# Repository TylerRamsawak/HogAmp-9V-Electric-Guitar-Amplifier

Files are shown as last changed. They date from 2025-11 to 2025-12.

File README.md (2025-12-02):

# HogAmp: 9V Electric Guitar Amplifier
I made a very simple, portable guitar amplifier. Its based off the LM386N-1 and is designed to run off a single 9V battery. I travel a lot to-and-fro school and bringing my 10W amp, while small, is becoming annoying. Its a bit too big to fit in a backpack and needs mains ac to run. With my amp, these problems are gone in exchange for power and quality. However, for practice, this is not a concern to me. The HogAmp's name is inspired by the Pignose brand of amps. Those are too expensive for me, so here is my compromise!
<br>
### 3D Render of Enclosure
render_top
render1
render_lid

<br>
<div class="table_component" role="region" tabindex="0">
<table>
    <caption>BOM</caption>
    <thead>
        <tr>
            <th>Reference</th>
            <th>Quantity</th>
            <th>Value</th>
            <th>LCSC ID</th>
            <th>Price</th>
            <th>Ext. Price</th>
        </tr>
    </thead>
    <tbody>
        <tr>
            <td>U1</td>
            <td>1</td>
            <td>LM386N-1</td>
            <td>N/A</td>
            <td>$0.85</td>
            <td>$1.70</td>
        </tr>
        <tr>
            <td>C1,C3</td>
            <td>2</td>
            <td>10uF</td>
            <td>N/A</td>
            <td>$0.09</td>
            <td>$0.18</td>
        </tr>
        <tr>
            <td>C2</td>
            <td>1</td>
            <td>1000uF</td>
            <td>N/A</td>
            <td>$0.30</td>
            <td>$0.30</td>
        </tr>
        <tr>
            <td>C4</td>
            <td>1</td>
            <td>330nF</td>
            <td>N/A</td>
            <td>$0.18</td>
            <td>$0.18</td>
        </tr>
      <tr>
            <td>J1,J3</td>
            <td>2</td>
            <td>Toggle Switch</td>
            <td>N/A</td>
            <td>$0.47</td>
            <td>$0.94</td>
        </tr>
      <tr>
            <td>J4,J5,J7</td>
            <td>3</td>
            <td>10k Log. Potentiometers</td>
            <td>N/A</td>
            <td>$0.50</td>
            <td>$1.50</td>
        </tr>
      <tr>
            <td>J4,J5,J7</td>
            <td>3</td>
            <td>Potentiometer Dust Seals</td>
            <td>N/A</td>
            <td>$0.04</td>
            <td>$0.12</td>
        </tr>
      <tr>
            <td>J2</td>
            <td>1</td>
            <td>1/4" Female Jack</td>
            <td>N/A</td>
            <td>$0.87</td>
            <td>$1.74</td>
        </tr>
      <tr>
            <td>BT1</td>
            <td>1</td>
            <td>9V Clip</td>
            <td>N/A</td>
            <td>$0.10</td>
            <td>$0.10</td>
        </tr>
        <tr>
            <td>Total: $6.67 + $16.44(cheapest shipping & tariff)</td>
        </tr>
      <tr>
            <td>Grand Total: $23.20</td>
        </tr>
    </tbody>
</table>
</div>
I bought some extras incase I blew something up. Also, since when was shipping so expensive?! This is the cheapest option. In the future, I will buy bulk components all at once.
<h3>3D Model</h3>

<h3>PCB</h3>

<h3>Schematic</h3>


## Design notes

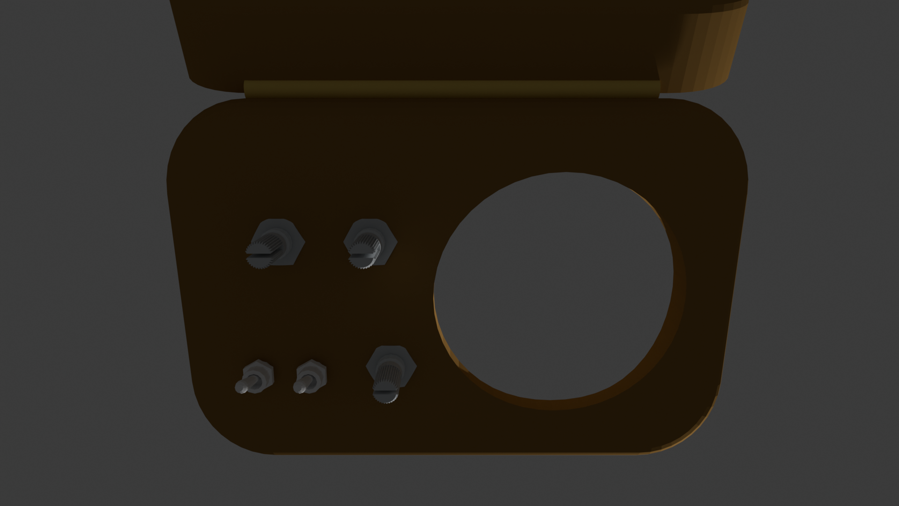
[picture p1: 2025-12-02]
render_lid.png

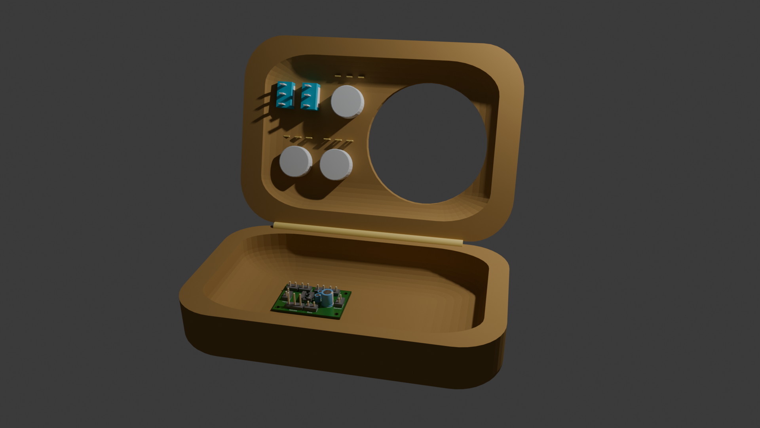
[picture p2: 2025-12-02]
render_side.png

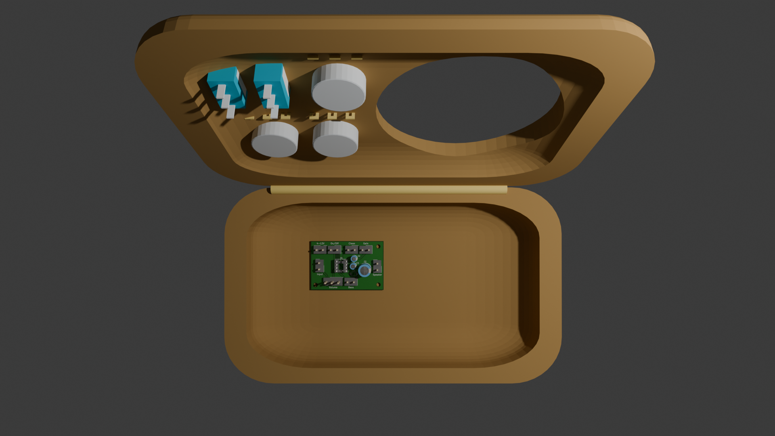
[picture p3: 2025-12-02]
render_top.png

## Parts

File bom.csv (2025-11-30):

Designator | Footprint | Quantity | Value | LCSC Part #
BT1 | Samtec_HPM-02-05-x-S_Straight_1x02_Pitch5.08mm | 1 | 9V
C1, C3 | CP_Radial_D5.0mm_P2.50mm | 2 | 10uF
C2 | CP_Radial_D10.0mm_P5.00mm | 1 | 1000uF
C4 | CAPRB500W50L450T300H550 | 1 | 330nF
J1 | Samtec_HPM-02-05-x-S_Straight_1x02_Pitch5.08mm | 1 | Power
J2 | Samtec_HPM-02-05-x-S_Straight_1x02_Pitch5.08mm | 1 | Jack
J3 | Samtec_HPM-02-05-x-S_Straight_1x02_Pitch5.08mm | 1 | Crunch
J4 | Samtec_HPM-02-05-x-S_Straight_1x02_Pitch5.08mm | 1 | Gain
J5 | Samtec_HPM-02-05-x-S_Straight_1x02_Pitch5.08mm | 1 | Bass
J6 | Samtec_HPM-02-05-x-S_Straight_1x02_Pitch5.08mm | 1 | Speaker
J7 | Samtec_HPM-03-01-x-S_Straight_1x03_Pitch5.08mm | 1 | Volume
U1 | DIP-8_W7.62mm_Socket | 1 | LM386

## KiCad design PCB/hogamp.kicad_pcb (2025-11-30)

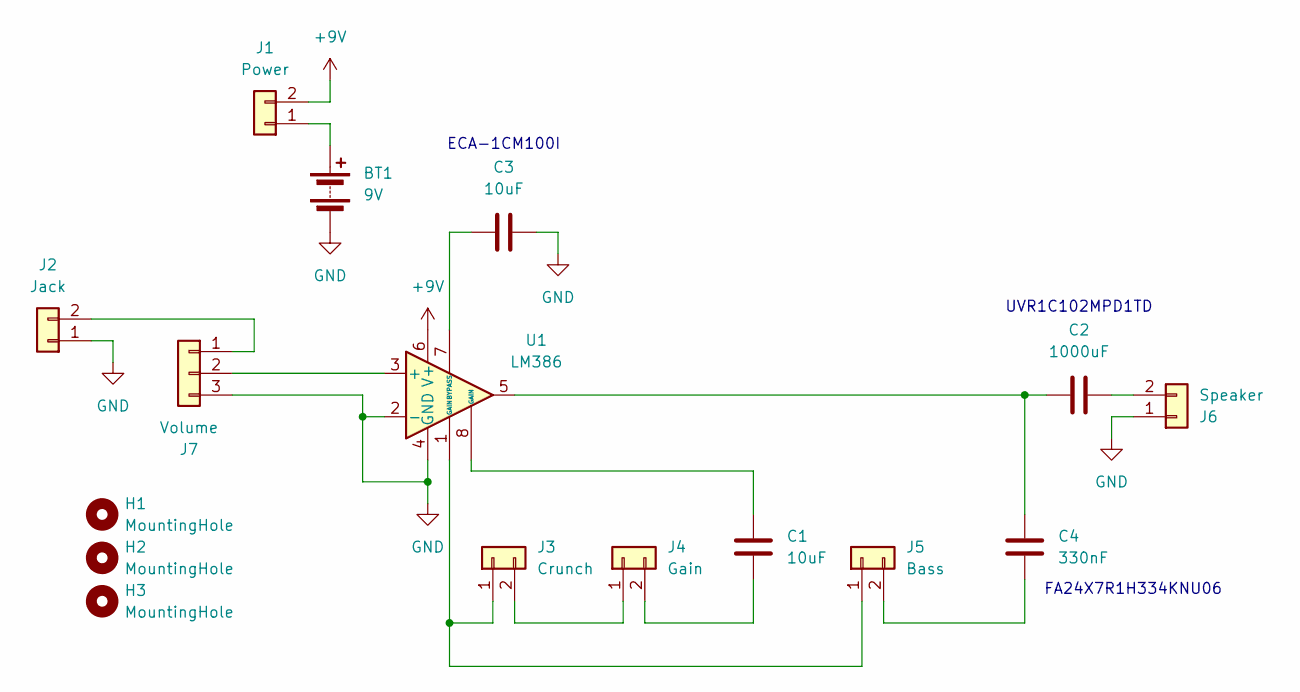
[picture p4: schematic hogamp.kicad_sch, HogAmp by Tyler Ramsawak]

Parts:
BT1: 9V; Samtec_HPM-02-05-x-S_Straight_1x02_Pitch5.08mm
C1, C3: 10uF; CP_Radial_D5.0mm_P2.50mm
C2: 1000uF; CP_Radial_D10.0mm_P5.00mm
C4: 330nF; CAPRB500W50L450T300H550
H1, H2, H3: MountingHole; MountingHole_3.2mm_M3
J1: Power; Samtec_HPM-02-05-x-S_Straight_1x02_Pitch5.08mm
J2: Jack; Samtec_HPM-02-05-x-S_Straight_1x02_Pitch5.08mm
J3: Crunch; Samtec_HPM-02-05-x-S_Straight_1x02_Pitch5.08mm
J4: Gain; Samtec_HPM-02-05-x-S_Straight_1x02_Pitch5.08mm
J5: Bass; Samtec_HPM-02-05-x-S_Straight_1x02_Pitch5.08mm
J6: Speaker; Samtec_HPM-02-05-x-S_Straight_1x02_Pitch5.08mm
J7: Volume; Samtec_HPM-03-01-x-S_Straight_1x03_Pitch5.08mm
U1: LM386; DIP-8_W7.62mm_Socket

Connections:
+9V: J1.2, U1.6 (V+)
GND: BT1.2 (-), C3.2, J2.1, J6.1, J7.3, U1.2 (-), U1.4 (GND)
unnamed: BT1.1 (+), J1.1
unnamed: C1.1, U1.8 (GAIN)
unnamed: C2.1, C4.1, U1.5
unnamed: J2.2, J7.1
unnamed: J3.1, J5.1, U1.1 (GAIN)
unnamed: J3.2, J4.1
unnamed: C1.2, J4.2
unnamed: C4.2, J5.2
unnamed: C2.2, J6.2
unnamed: J7.2, U1.3 (+)
unnamed: C3.1, U1.7 (BYPASS)

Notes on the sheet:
ECA-1CM100I
FA24X7R1H334KNU06
UVR1C102MPD1TD

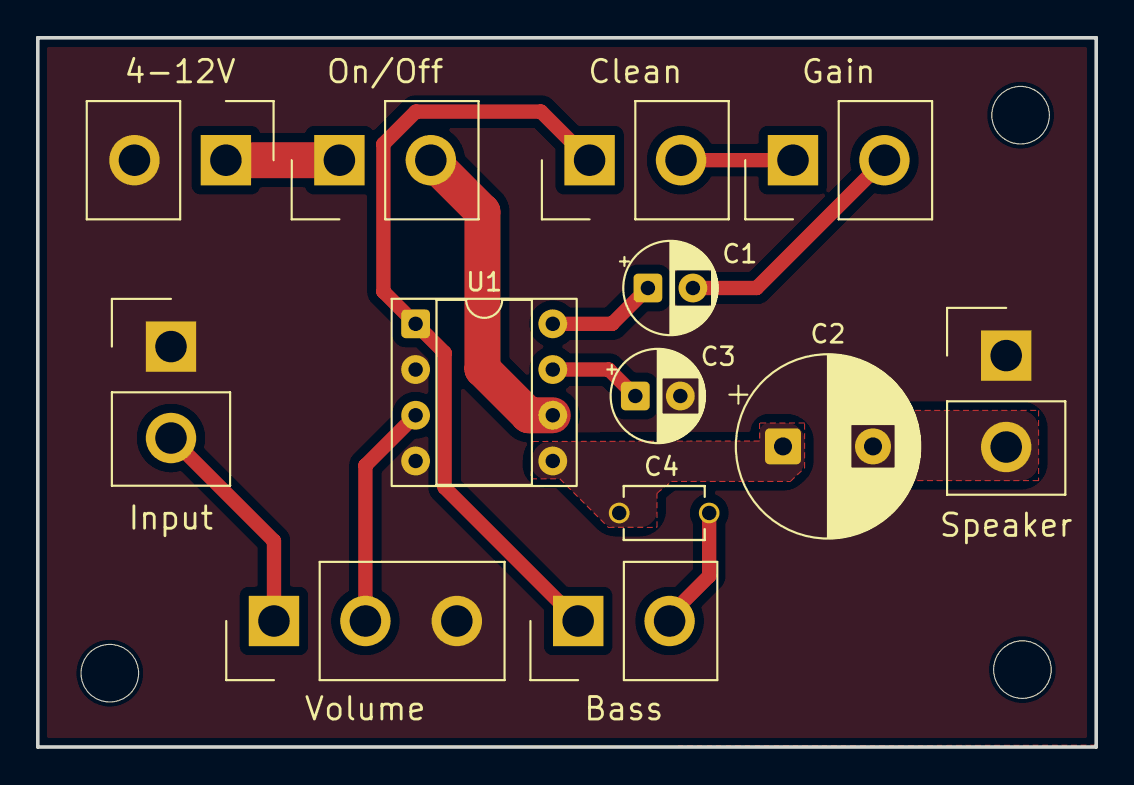
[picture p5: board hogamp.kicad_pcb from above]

Board: 2 copper layers, 58.8 x 39.4 mm, 16 parts (0 on the bottom side), 13 nets.

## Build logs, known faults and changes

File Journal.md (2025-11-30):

Total Time: 8.8Hrs<br>
11/29/2025 to 11/30/2025<br>

# Finished PCB Layout
Here is what I came up with, I mainly just placed things randomly until I got it to a good size. Its quite a small board at only 60x40mm. Itll be sure to fit in the enclosure I plan on using, which is a very small cigar box. I will mount the PCB using 3 M3 screws and nuts. The potentiometers, switches, and jacks will be panel mounted, too.
Here is the final PCB layout:

And the 3D render:

And my final schematic:


# Component Selection and Footprints
This part always takes the longest. For the LM386, I used the standard DIP-8 package. For the caps, I always use TDK, Panasonic, or Nichicon. I chose the cheapest THT values and simply selected their footprints based off their datasheet or what Digikey told me. I look here:

For the potentiometers, jacks, and switches, I will buy those off of amazon because it is much cheaper than Digikey for these generic parts, in my experience. They will be case mounted, so I need to simplify my schematic to reflect that these will be connectors: 

and all of my footprints:

Now I will lay out the PCB.

# Designed Circuit
For my amp, I chose the LM386 because I've learned about them already and they seem to be ubiquitous in their use in low-power guitar amps. I chose the N-1 variant because it operates about my 9V voltage level ranging 5-12V. First, I made the 1/4" input stage which consists of a logarithmic 10k potentiometer going straight to the non-inverting input. The 10k was chosen to be logarithmic because this is to control the volume.


Next, I need to design the gain control. This is simply a 10k log. pot in series with a 10uF capacitor and a SPST switch across pins 1 and 8 of the amp. The capacitor value was taken from the datasheet.

This allows the amp to vary its gain from a ratio of 20 up to 200, which is cool! The switch is there to toggle between clean and dirty, naturally.

Next was bass control. By placing a capacitor between pins 5 and 1, high frequencies are attenuated since Xc is inversely proportional to f. As f increases, C shunts that high frequency, leaving more perceivable bass. The R is for shaping, i think.

Lastly was the 1000uF capacitor in series with the 8 Ohm speaker. This coupling capacitor charges up to effectively remove DC offset bias which could harm the speaker. It only allows AC through. The higher the value, the lower the frequencies will be able to pass through. For example, if f=100Hz, Xc=1/2pi(100Hz)(1000x10^-6)=1.6Ohms of resistance. The higher C, the lower Xc will be for a given f. By having our coupling cap at sucha high value, I hope I will get a nice bass throughput.

I have not placed any LEDs to let you know its on to save power.

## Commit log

2025-11-30 Revise README with detailed project description
    Expanded the README to provide a detailed description of the HogAmp, including its purpose, components, and pricing. Added sections for 3D model, PCB, and schematic images.
2025-11-30 Add journal entry for PCB design and circuit details
    Documented the PCB layout, component selection, and designed circuit for an audio amplifier using the LM386. Included images of the layout, schematic, and component footprints.
2025-12-02 Include 3D renders in README
    Added 3D renders of the amplifier enclosure to the README.
